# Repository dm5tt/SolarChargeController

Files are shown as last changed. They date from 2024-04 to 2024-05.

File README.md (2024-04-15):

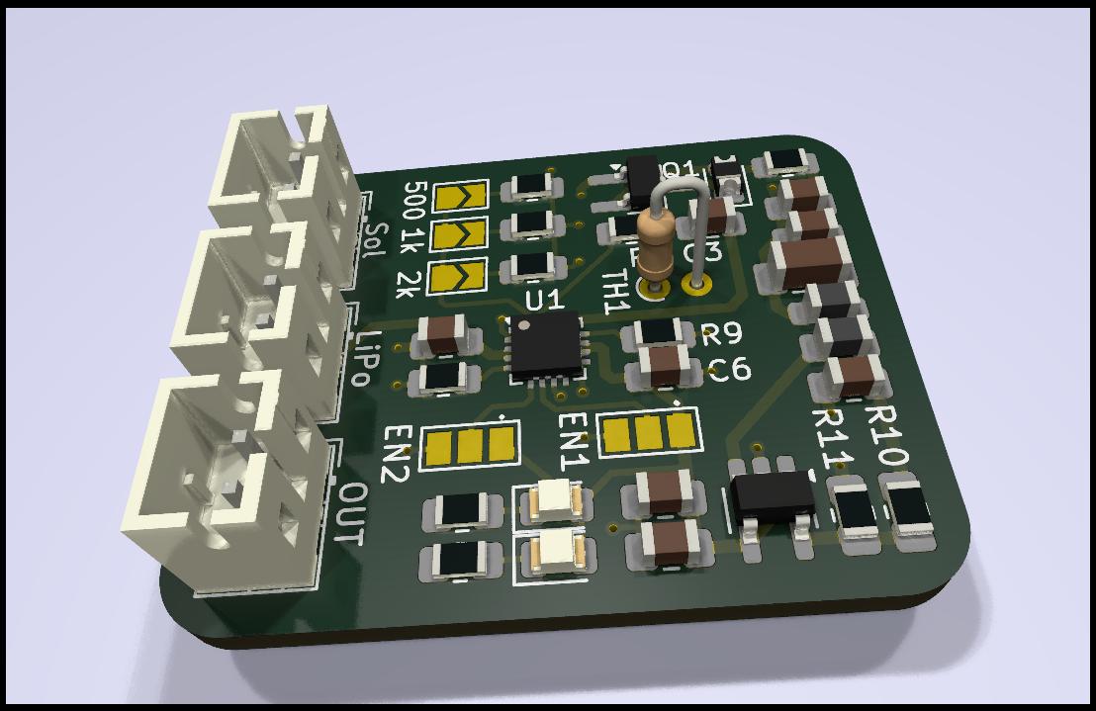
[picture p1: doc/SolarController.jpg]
Solar Charge Controller


# Description

A small TI BQ24074 solar charger inspired by the Adafruit design with some modifications:

 - Protection diode replaced with a PMOS to get rid of the diode voltage drop
 - Added a M3406-ADJ to get clean 3.3V
 - Big Cs to catch transients
 - Filter to get rid of most of the ripple caused by the buck

# Important

Thermistor TH1 must *always* be soldered. 

If you don't want to use one: solder a 10k 0805 resistor.

# Configuration

| **OUT Voltage** | **R10** | **R11** |
|---|---|---|
| 1.8V |  Todo | Todo |
| 3.3V |  Todo | Todo |

| **Charging current max.** | **EN1** | **EN2** |
|---|---|---|
|  500mA | Dot |  No Dot |
|  100mA | No Dot |  No Dot |

# Most important datasheets

[TI BQ24074](https://www.ti.com/lit/gpn/bq24074)

[XI'AN Aerosemi Tech M3406-ADJ](https://www.lcsc.com/datasheet/lcsc_datasheet_2304140030_XI-AN-Aerosemi-Tech-M3406-ADJ_C83224.pdf)

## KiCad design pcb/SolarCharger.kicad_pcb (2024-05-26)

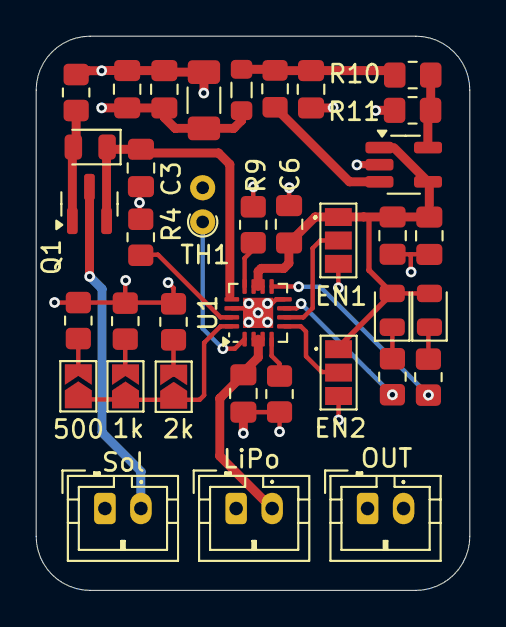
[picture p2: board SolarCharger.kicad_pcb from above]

Board: 4 copper layers, 24.1 x 30.8 mm, 37 parts (0 on the bottom side), 24 nets.

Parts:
C1: 4.7uF; C_0805_2012Metric_Pad1.18x1.45mm_HandSolder
C2, C6, C7: 1uF; C_0805_2012Metric_Pad1.18x1.45mm_HandSolder
C3: 42uF; C_0805_2012Metric_Pad1.18x1.45mm_HandSolder
C4: 10uF; C_0805_2012Metric_Pad1.18x1.45mm_HandSolder
C5, C8: 0.1uF; C_0805_2012Metric_Pad1.18x1.45mm_HandSolder
C9: 100uF; C_1206_3216Metric_Pad1.33x1.80mm_HandSolder
D1, D2: LED; LED_0805_2012Metric
D3: D_Schottky; D_0805_2012Metric
FB2: FerriteBead_Small; L_0805_2012Metric_Pad1.05x1.20mm_HandSolder
J1, J2, J3: Conn_01x02_Pin; JST_PH_B2B-PH-K_1x02_P2.00mm_Vertical
JP1, JP2, JP3: SolderJumper_2_Open; SolderJumper-2_P1.3mm_Open_TrianglePad1.0x1.5mm
JP4, JP5: SolderJumper_3_Open; SolderJumper-3_P1.3mm_Open_Pad1.0x1.5mm_NumberLabels
L1: 2.2uH; L_0805_2012Metric_Pad1.15x1.40mm_HandSolder
Q1: AO3401A; SOT-23
R1: 590; R_0805_2012Metric_Pad1.20x1.40mm_HandSolder
R2, R9: 1k; R_0805_2012Metric_Pad1.20x1.40mm_HandSolder
R3: 2k; R_0805_2012Metric_Pad1.20x1.40mm_HandSolder
R4, R5, R6, R7: 10k; R_0805_2012Metric_Pad1.20x1.40mm_HandSolder
R8: 100k; R_0805_2012Metric_Pad1.20x1.40mm_HandSolder
R10, R11: R; R_0805_2012Metric_Pad1.20x1.40mm_HandSolder
TH1: Thermistor; R_Axial_DIN0204_L3.6mm_D1.6mm_P1.90mm_Vertical
U1: BQ24074; VQFN-16-1EP_3x3mm_P0.5mm_EP1.68x1.68mm
U2: M3406-ADJ; SOT-23-5_HandSoldering

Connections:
+3.3V: C7.1, C8.1, C9.1, FB2.2, J3.2
/OUT: C1.1, C5.1, C6.2, D1.2 (A), D2.2 (A), JP4.3 (B), JP5.3 (B), U1.10 (OUT), U1.11 (OUT), U2.1 (RUN), U2.4 (VIN)
/VBUS: C3.1, D3.1 (K), Q1.2 (S), U1.13 (IN)
/VLIPO: C2.2, J1.2, U1.2 (BAT), U1.3 (BAT)
GND: C1.2, C2.1, C3.2, C4.2, C5.2, C6.1, C7.2, C8.2, C9.2, J1.1, J2.1, J3.1, JP4.1 (A), JP5.1 (A), R1.1, R2.1, R3.1, R4.2, R5.2, R8.1, R9.1, R11.2, TH1.2, U1.8 (Vss), U1.14 (TMR), U1.17 (Vss), U2.2 (GND)
unnamed: C4.1, FB2.1, L1.2, R10.1
unnamed: D1.1 (K), R7.2
unnamed: D2.1 (K), R6.2
unnamed: D3.2 (A), Q1.1 (G), R8.2
unnamed: J2.2, Q1.3 (D)
unnamed: JP1.1 (A), JP2.1 (A), JP3.1 (A), U1.16 (ISET)
unnamed: JP1.2 (B), R1.2
unnamed: JP2.2 (B), R2.2
unnamed: JP3.2 (B), R3.2
unnamed: JP4.2 (C), U1.6 (EN1)
unnamed: JP5.2 (C), U1.5 (EN2)
unnamed: R5.1, U1.4 (CE)
unnamed: R6.1, U1.9 (CHG)
unnamed: R9.2, U1.12 (ILIM)
unnamed: R4.1, U1.15 (ITERM)
unnamed: R7.1, U1.7 (PGOOD)
unnamed: TH1.1, U1.1 (TS)
unnamed: R10.2, R11.1, U2.5 (FB)
unnamed: L1.1, U2.3 (SW)

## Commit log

2024-04-17 pcb: smaller eyecandy stuff. No functional changes.
    [SolarCharger.kicad_pcb]
2024-04-17 doc: replace with with new pcb
2024-04-17 pcb: eyecandy stuff destoryed the solderbridge marker
    [SolarCharger.kicad_pcb]
2024-05-26 pcb, schematic: get rid of non-standard p-mosfet and replace it with an AO3401
    [SolarCharger.kicad_pcb]
